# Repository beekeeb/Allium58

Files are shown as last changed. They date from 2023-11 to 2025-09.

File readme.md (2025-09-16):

# Allium58

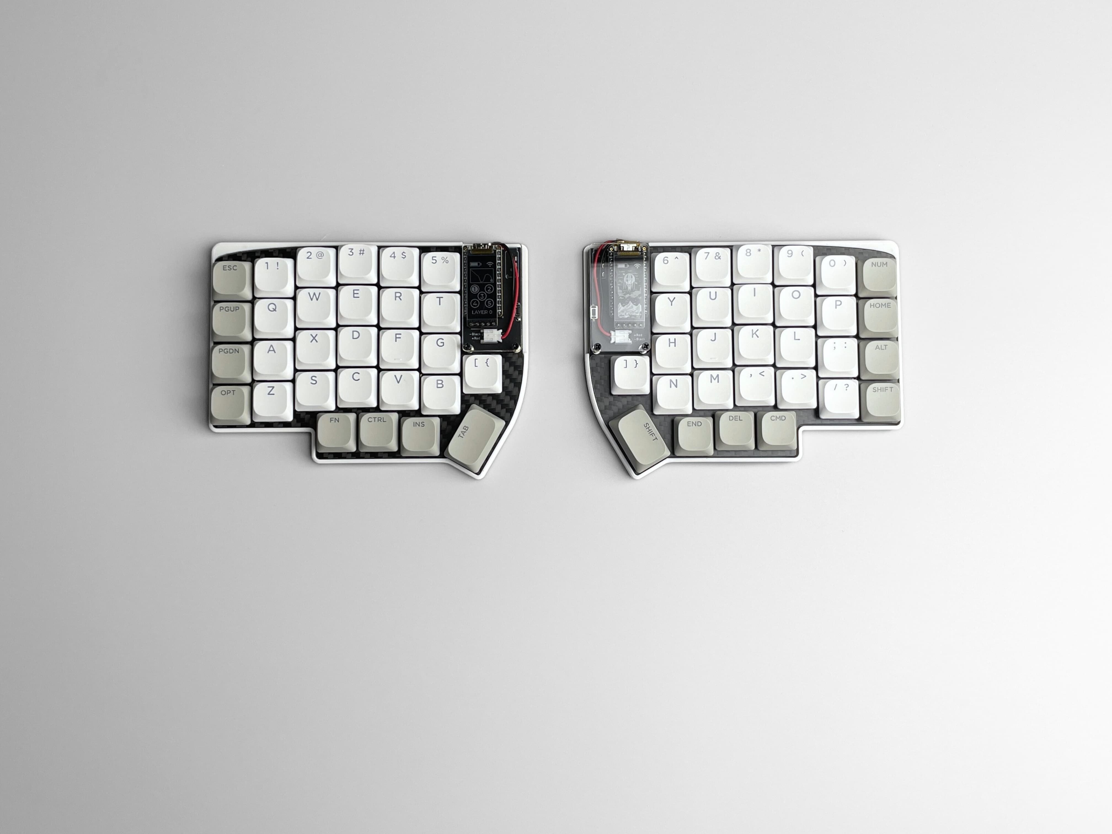
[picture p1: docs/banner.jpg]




The Allium58 is an open source 6*4+4keys column-staggered split keyboard. It is based on [Lily58 Pro created by kata0510](https://github.com/kata0510/Lily58/tree/master/Pro). The Allium58 shares the same layout as the Lily58 Pro and also supports using the original Lily58 Pro firmware. However, several changes have been made to the board:

- **Enhanced Wireless Capability:** The Allium58 is designed to be more suitable for wireless builds. It provides native support for utilizing power-saving nice!view or other memory-in-pixel displays. This allows for efficient power management and extended battery life.

- **Improved Battery Management:** To enhance battery management, power switches and JST battery sockets have been added to the Allium58. These additions make it easier to control power supply and facilitate seamless battery replacement.

- **GLP (Gateron Low Profile) Socket Compatibility:** A variant of Allium58 that works with Gateron Low Profile sockets. This allows for the use of Gateron KS-27/KS-33 low-profile key switches.

## Status

| Variant  | Status  |
| --- | --- |
| GLP (Gateron Low Profile) | Ready  |
| MX & Choc  | WIP  |

## Photos

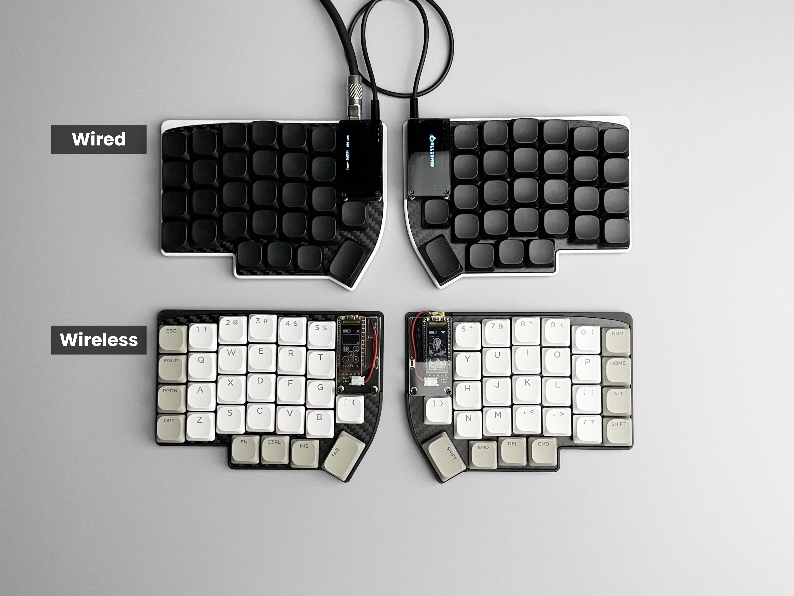
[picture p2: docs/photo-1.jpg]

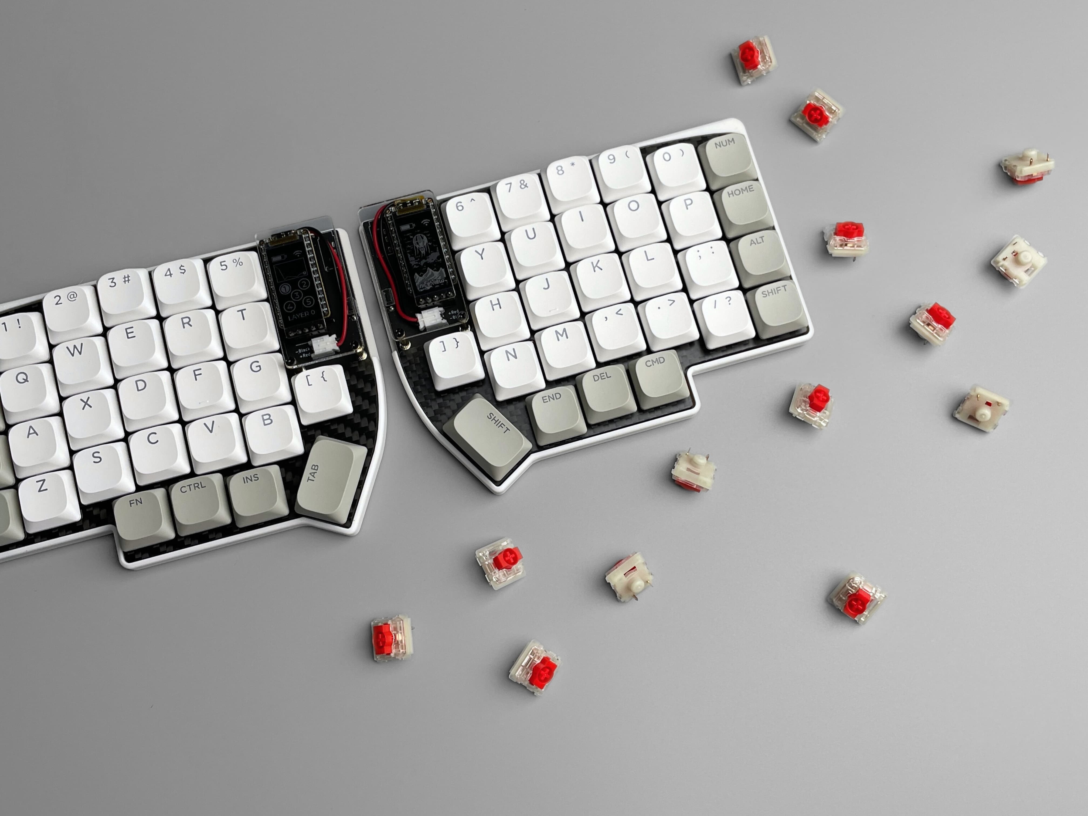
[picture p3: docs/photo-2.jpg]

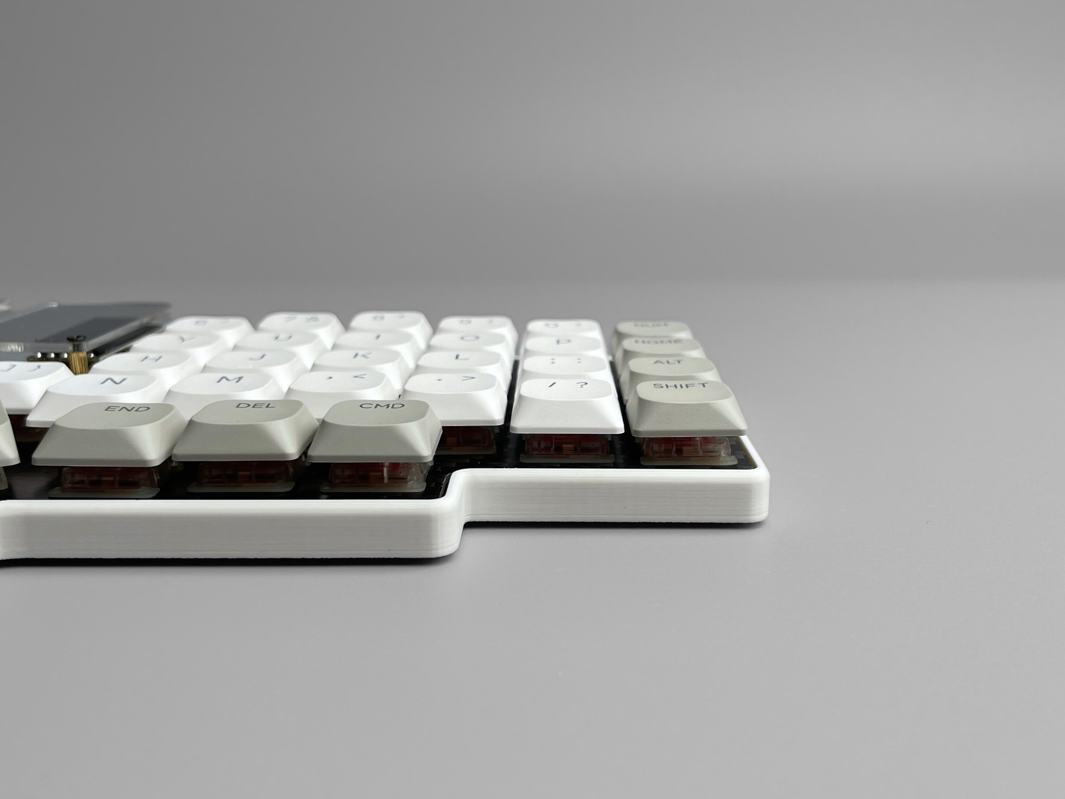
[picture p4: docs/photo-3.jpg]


## Bill of Materials (BOM)

### Required

| Name | Count | Remarks |
|:-|:-|:-|
| PCB | 1 set | |
| Top plate | 2 sheets | 1.2mm thick |
| Bottom plate / 3D printed case | 1 set | |
| OLED cover | 2 | |
| Pro Micro (compatible with Sea Picro RP2040) / nice!nano or equivalent | 2 |  |
| Reset button | 2 | TS-1136 THT |
| Diodes | 58 | SMD Only (SOD-123 Package) |
| Hotswap Sockets | 58 | [GLP variant] Gateron Low Profile Hotswap Sockets |
| Key switches | 58 | [GLP variant] Gateron KS-33 / KS-27 |
| Keycaps | 58 pieces | 1u 56 pcs, 1.5u 2 pcs [GLP Keycaps Comparison](https://showcase.beekeeb.com/the-keycaps-of-gateron-low-profile-key-switches-and-kailh-choc-v1-key-switch/) |
| Female Threaded Brass Spacer M2 5mm | 10 pieces | For Case assembly |
| Female Threaded Brass Spacer M2 9mm (or 14mm with MCU sockets) | 4 pieces | For OLED cover |
| GP823 Screw M2 4mm | 28 screws | |
| [Wired build] TRRS (4 poles) cable | 1 |  |
| [Wired build] TRRS jack | 2 |  |
| [Wired build] Micro USB or USB-C cable | 1 | Avoid charge-only cables |
| [Wireless build] JST battery socket | 2 | |
| [Wireless build] Battery with JST connector | 2 | |
| [Wireless build] Battery / power switch | 2 | IS-1290A-W-G / MSK12C02 / SSSS811101 |

### Optional

| Name | Count | Remarks |
|:-|:-|:-|
| OLED module / nice!view display | 2 | |
| Microcontroller / OLED Sockets & Pins | 1 set |  |

## Case
- Top Plate & Low Profile Bottom Case: https://www.printables.com/model/657755-low-profile-case-for-allium58-glp

## Firmware

- Wired: [QMK](https://github.com/qmk/qmk_firmware "QMK") - compatible with `lily58/rev1`
- Wired: [Vial](https://github.com/vial-kb/vial-qmk "Vial") (based on QMK) - supported
- Wireless: [ZMK](https://github.com/zmkfirmware/zmk "ZMK") - supported

## Ordering Parts

- Wired: https://shop.beekeeb.com/product/allium58-glp-wired-kit/
- Wireless: https://shop.beekeeb.com/product/allium58-glp-wireless-kit/

## External Libraries

* [https://github.com/siderakb/key-switches.pretty](https://github.com/siderakb/key-switches.pretty)
* [https://github.com/foostan/kbd](https://github.com/foostan/kbd)

## More Information

* [A great doc about Gateron Low Profile switches writen by Rafael Yumagulov](https://ergonautkb.github.io/docs/switches/gateron-low-profile/)
* [Keycaps for Gateron Low Profile Key Switches](https://showcase.beekeeb.com/the-keycaps-of-gateron-low-profile-key-switches-and-kailh-choc-v1-key-switch/)

## Credits

This open source hardware project is created by [beekeeb](https://beekeeb.shop) and other contributors. It is based on [Lily58 Pro created by kata0510](https://github.com/kata0510/Lily58/tree/master/Pro).

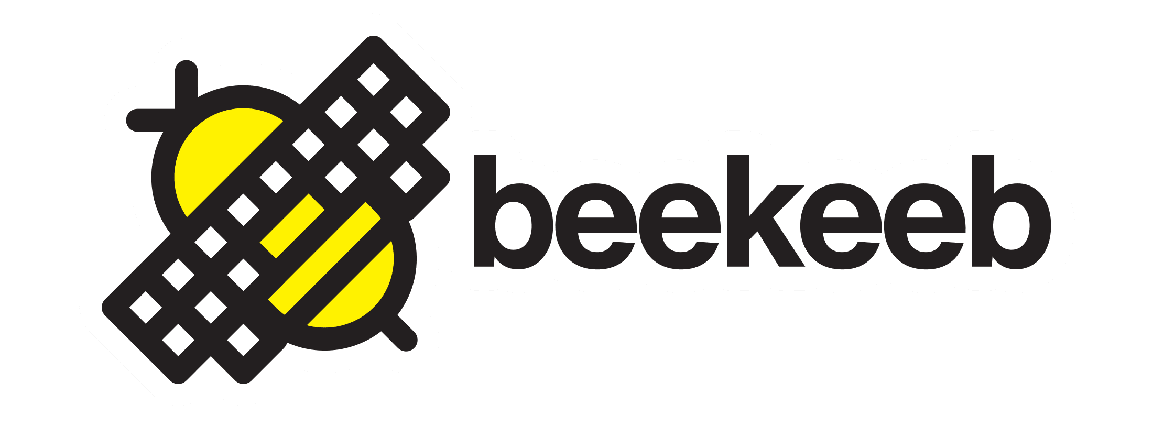
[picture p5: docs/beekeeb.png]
[](https://beekeeb.shop)

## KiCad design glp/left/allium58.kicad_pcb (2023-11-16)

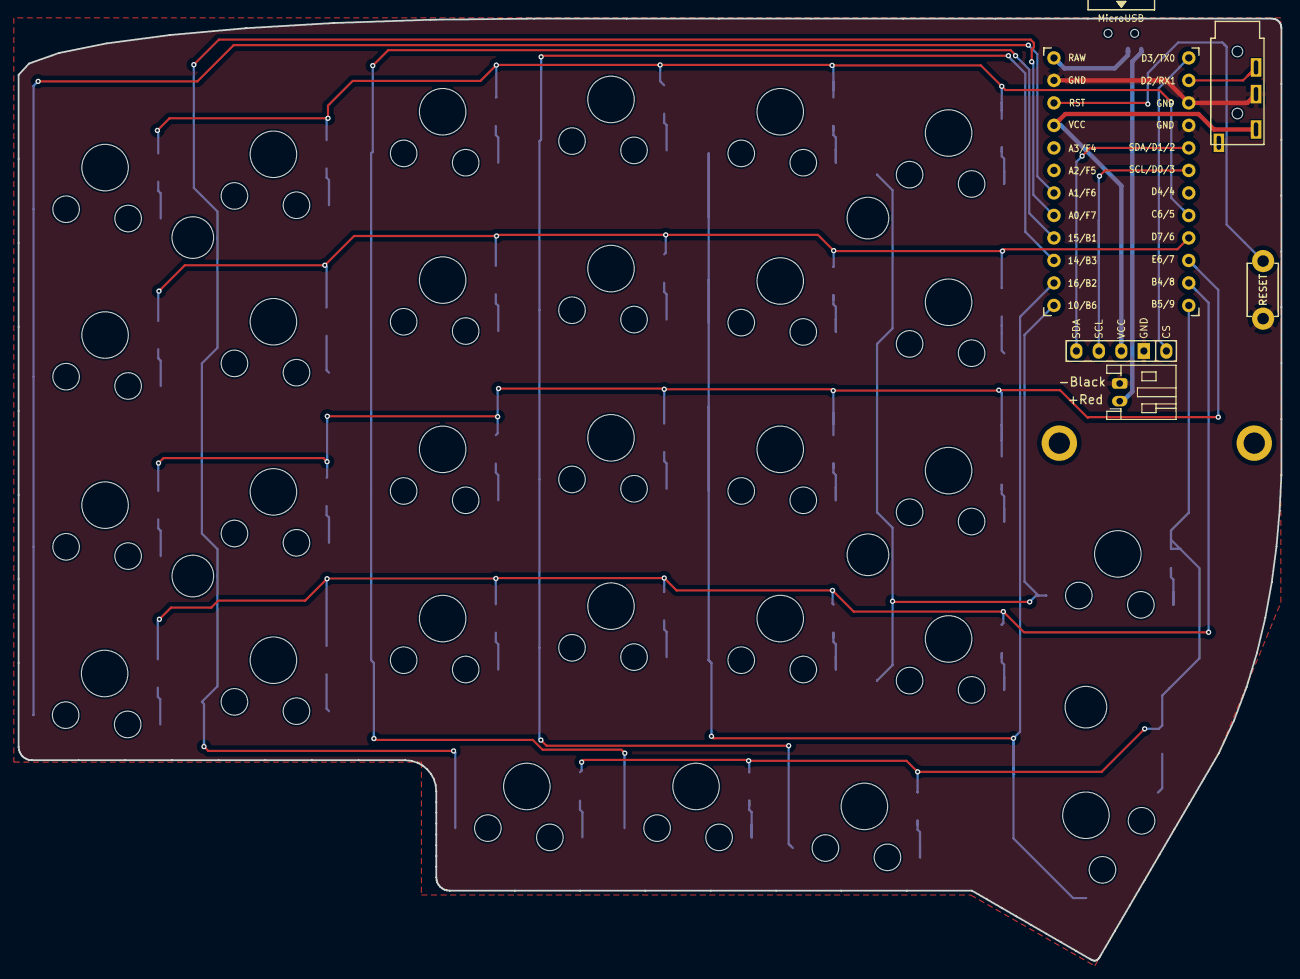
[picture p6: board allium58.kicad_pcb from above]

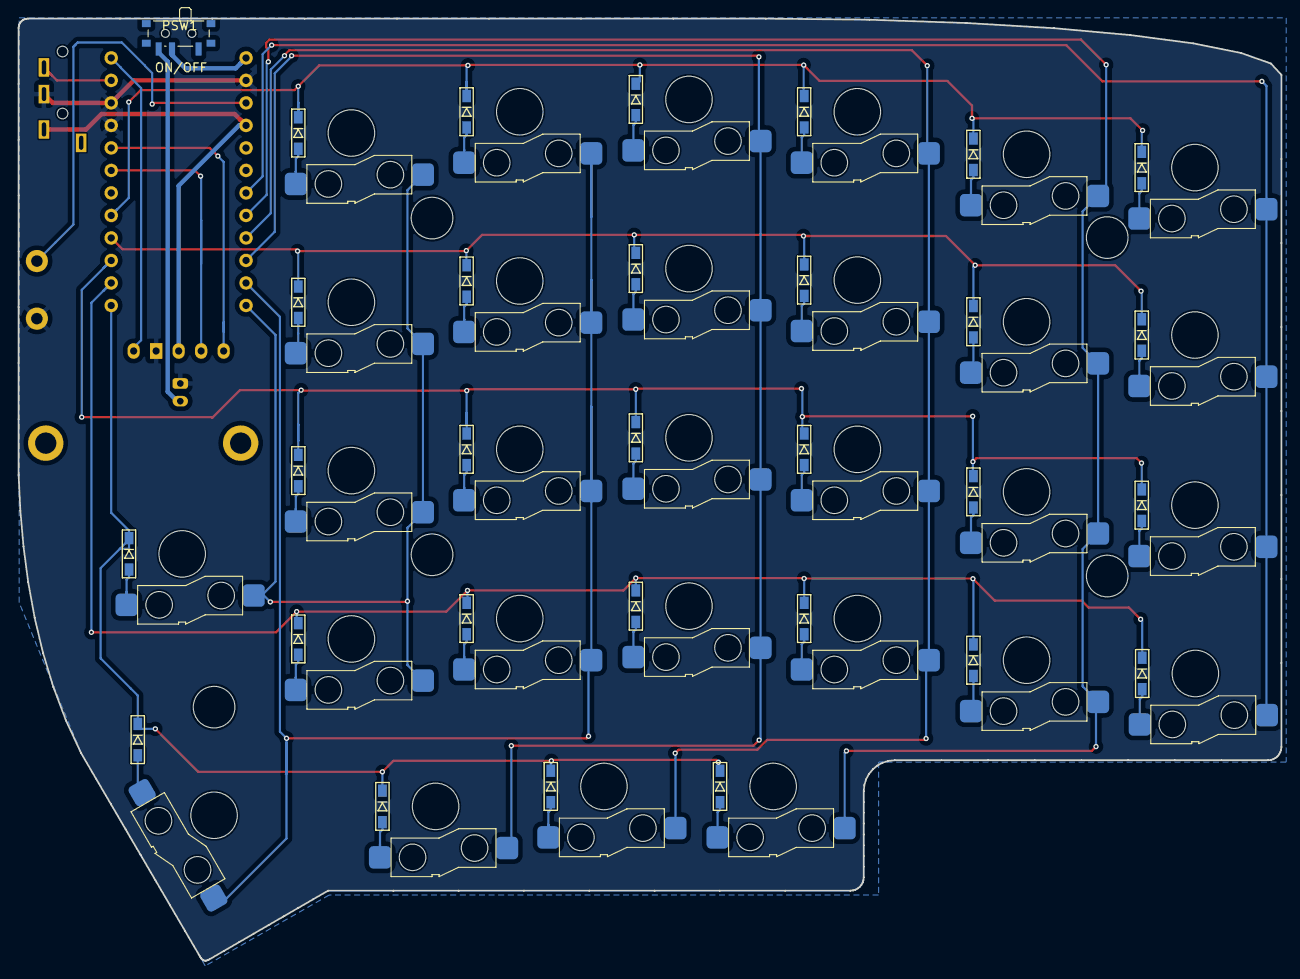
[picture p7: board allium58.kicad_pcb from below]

Board: 2 copper layers, 142.5 x 106.3 mm, 71 parts (37 on the bottom side), 49 nets.

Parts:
BATJ1: Conn_01x02_Female; JST_PH_S2B-PH-K_1x02_P2.00mm_Horizontal
D1, D2, D3, D4, D5, D6, D7, D8, D9, D10, D11, D12, D13, D14, D15, D16, D17, D18, D19, D20, D21, D22, D23, D24, D25, D26, D27, D28, D29: D; D3_SMD_v2
J2: 4PIN; MJ-4PP-9
J3: OLED; nice_view_1side
PSW1: SW_SPST; SW_SPDT_PCM12
RSW1: SW_RST; TACT_SWITCH_TVBP06
SW1, SW2, SW3, SW4, SW5, SW6, SW7, SW8, SW9, SW10, SW11, SW12, SW13, SW14, SW15, SW16, SW17, SW18, SW19, SW20, SW21, SW22, SW23, SW24, SW25, SW26, SW27, SW28, SW29: SW_PUSH; SW_Gateron_LowProfile_HotSwap
TH1, TH2: HOLE; M2_HOLE_PCB
TH3, TH4, TH5, TH6, TH7: HOLE; HOLE_M2_TH
U1: ProMicro; ProMicro_v3

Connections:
+BATT: BATJ1.1, PSW1.3 (C)
CS: J3.5, U1.1 (TX(PD3))
DATA: J2.3, U1.2 (RX(PD2))
GND: BATJ1.2, J2.2, J3.4, RSW1.1, U1.3 (GND), U1.4 (GND), U1.23 (GND)
unnamed: D1.2 (A), SW1.2
unnamed: D2.2 (A), SW2.2
unnamed: D3.2 (A), SW3.2
unnamed: D4.2 (A), SW4.2
unnamed: D5.2 (A), SW5.2
unnamed: D6.2 (A), SW6.2
unnamed: D7.2 (A), SW7.2
unnamed: D8.2 (A), SW8.2
unnamed: D9.2 (A), SW9.2
unnamed: D10.2 (A), SW10.2
unnamed: D11.2 (A), SW11.2
unnamed: D12.2 (A), SW12.2
unnamed: D13.2 (A), SW13.2
unnamed: D14.2 (A), SW14.2
unnamed: D15.2 (A), SW15.2
unnamed: D16.2 (A), SW16.2
unnamed: D17.2 (A), SW17.2
unnamed: D18.2 (A), SW18.2
unnamed: D19.2 (A), SW19.2
unnamed: D20.2 (A), SW20.2
unnamed: D21.2 (A), SW21.2
unnamed: D22.2 (A), SW22.2
unnamed: D23.2 (A), SW23.2
unnamed: D24.2 (A), SW24.2
unnamed: D25.2 (A), SW25.2
unnamed: D26.2 (A), SW26.2
unnamed: D27.2 (A), SW27.2
unnamed: D28.2 (A), SW28.2
unnamed: D29.2 (A), SW29.2
RESET: RSW1.2, U1.22 (RST)
SCL: J3.2, U1.6 (SCL(PD0))
SDA: J3.1, U1.5 (SDA(PD1))
VCC: J2.1, J3.3, U1.21 (VCC)
col0: SW6.1, SW12.1, SW18.1, SW24.1, U1.18 (A1(PF6))
col1: SW5.1, SW11.1, SW17.1, SW23.1, SW29.1, U1.17 (A0(PF7))
col2: SW4.1, SW10.1, SW16.1, SW22.1, SW28.1, U1.16 (D15(PB1))
col3: SW3.1, SW9.1, SW15.1, SW21.1, SW27.1, U1.15 (D14(PB3))
col4: SW2.1, SW8.1, SW14.1, SW20.1, SW26.1, U1.14 (D16(PB2))
col5: SW1.1, SW7.1, SW13.1, SW19.1, SW25.1, U1.13 (D10(PB6))
raw: PSW1.2 (B), U1.24 (RAW)
row0: D1.1 (K), D2.1 (K), D3.1 (K), D4.1 (K), D5.1 (K), D6.1 (K), U1.8 (D5(PC6))
row1: D7.1 (K), D8.1 (K), D9.1 (K), D10.1 (K), D11.1 (K), D12.1 (K), U1.9 (D6(PD7))
row2: D13.1 (K), D14.1 (K), D15.1 (K), D16.1 (K), D17.1 (K), D18.1 (K), U1.10 (D7(PE6))
row3: D19.1 (K), D20.1 (K), D21.1 (K), D22.1 (K), D23.1 (K), D24.1 (K), U1.11 (D8(PB4))
row4: D25.1 (K), D26.1 (K), D27.1 (K), D28.1 (K), D29.1 (K), U1.12 (D9(PB5))

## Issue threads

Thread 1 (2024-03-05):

ETA  on MX & Choc variants?

bakerbrandond, 2024-03-05:
This looks great.  Do you have an ETA for the MX and Choc versions?

happy42779, 2024-03-14:
Same here, excited about the MX variants. GLP switches are a little expensive.

zxku, 2024-04-26:
FYI Beekeeb has the MX and Choc version for sale on his site.  Both as a kit and as a pre-built.  I know because I ordered one. Ha!

spikespaz, 2024-09-07:
@zxku Mind sharing a link? I wasn't able to find it.

zxku, 2024-09-08:
[Allium58-choc](https://shop.beekeeb.com/product/wireless-allium58-choc/)I didn’t see it as a DIY kit, but clearly he has the parts. I’d email and ask him if you want a kit and not a pre-built version. He’s pretty responsive to emails. Cheers,Zac Morhous______________________________________________________________________________Zac MorhousEngineering LeadMicro-LAM Technologies, LLCPhone: +1 (734) 320 5758Website: www.micro-lam.comOn Sep 7, 2024, at 7:11 AM, Jacob Birkett ***@***.***> wrote:
@zxku Mind sharing a link? I wasn't able to find it.

—Reply to this email directly, view it on GitHub, or unsubscribe.You are receiving this because you were mentioned.Message ID: ***@***.***>

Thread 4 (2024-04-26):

Spacer M2 5mm -> Threaded M2 Spacer 5mm

zxku, 2024-04-26:
I was confused about how you put this thing together until I realized that the brass spacers you specify for use are threaded.  Typically the term "M2 spacer" would refer to an unthreaded tube who's inner diameter is selected to slide over the outer diameter of an M2 screw.  A _threaded_ M2 spacer, is the term. to describe a tube with a threaded hole through the center.

I would recommend at least changing the documentation to "Threaded M2 spacer" to avoid confusion.

_In this case, I think that would be good enough to avoid confusion, which is the important part.  However the technically correct terminology would actually call it a female threaded spacer, and should also specify the thread pitch in addition to the thread diameter and length._  They are also sometimes specified as a female threaded tube.

torytang, 2024-04-27:
Thank you @zxku :)

I updated the readme.

Closed 2024-04-27.

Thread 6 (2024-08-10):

Battery Power Not Functioning on Allium58 Split Keyboard with Nice!Nano V2

foprel, 2024-08-10:
Hello 👋🏻

I've recently assembled the Allium58 split keyboard using the Nice!Nano V2 controller and ZMK firmware. While the keyboard functions perfectly when the left half is connected to my MacBook Pro via a USB-C cable, I encounter issues when trying to power the board solely with a battery. The keyboard does not seem to power on wirelessly using the battery.

**Setup Details:**
- Mode: Wireless
- Controller: Nice!Nano V2
- Battery: 301230 110mAh
- Firmware: ZMK

**Steps Taken:**
- Left Half: Works when connected via a USB-C data cable.
- Right Half: Works when connected via a USB-C data cable.
- Bluetooth Connectivity: Right half can connect via Bluetooth when the left half is connected via USB-C.
- Battery Connection: Confirmed battery polarity before attachment.

**Observations:**
- Using a multimeter, I detected no voltage on the `RAW` and `GND` pins on the Allium58 PCB when the battery is connected to the JST connector.
- Similarly, I observed no voltage on the `ON/OFF` circuit.
- From the PCB design, it appears that the `ON/OFF` circuit is directly connected to the JST connector. Can you confirm if this is correct?

**Possible Issue:**
I suspect that there might be an issue with my soldering of the `ON/OFF` circuit, which could be preventing the board from powering on via battery. However, I'm not entirely sure if this is the root cause or if there's something else I might have missed.

**Request for Assistance:**
I would greatly appreciate any guidance or suggestions from the community or the creator on how to troubleshoot this issue further. Has anyone else experienced similar problems, or could this be indicative of a potential fault in my assembly? Any insights that could point me in the right direction would be very helpful.

Thank you for your time and support!

foprel, 2024-08-15:
I have traced the problem using a multimeter. It turned out there were several cold solder joints. After resoldering the `ON/OFF` switch, the problem was solved.

Closed 2024-08-15.

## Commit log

2023-11-24 Add links to case files
2025-06-10 Added battery- / power switch Added part numbers for reset button and battery- / power switch

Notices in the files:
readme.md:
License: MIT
